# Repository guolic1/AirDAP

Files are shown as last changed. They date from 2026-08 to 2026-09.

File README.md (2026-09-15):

# AirDAP

基于 ESP32-S3 的无线调试器，支持 CMSIS-DAP 调试烧录和串口通信。
通过 USB 直连，或使用 Windows / Linux 主机服务将网络设备映射为 USB 调试器和串口。

支持蓝牙 / USB 配网、Wi-Fi 扫描、设备信息查看及 OTA 升级。

## 快速开始

从 [Releases](https://github.com/guolic1/AirDAP/releases/latest) 下载服务管理器和固件：

- **Windows**：双击服务管理器安装服务，可设置端口和开机自启。默认管理地址为 `http://airdap.localhost:8080`。
- **Linux**：按 [主机服务说明](host/README.md) 构建并安装 systemd 服务。
- **固件**：`app.bin` 用于 OTA；`full.bin` 用于首次烧录或恢复，写入地址为 `0x0`，会清除配网数据。

Windows 的 USB/IP 映射需安装 [usbip-win2 驱动和客户端](https://github.com/vadimgrn/usbip-win2/releases)。

## 项目目录

- [firmware/](firmware/README.md)：ESP-IDF 固件与构建说明。
- [host/](host/README.md)：Rust 主机服务、Web 管理页和服务安装工具。
- [circuit/](circuit/)：KiCad 原理图与 PCB。
- [docs/hardware-pinmap.md](docs/hardware-pinmap.md)：硬件引脚约定。

## 许可证

[MIT](LICENSE)。第三方依赖遵循各自的许可证。

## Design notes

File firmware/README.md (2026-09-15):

# 固件构建

目标芯片为 ESP32-S3，使用 ESP-IDF v6.1.0。准备 Git、Python 3.13+；Windows 还需安装 `uv`。首次配置需要联网，工具安装在 `firmware/.airdap-env/`。

## Windows（PowerShell）

从仓库根目录执行：

```powershell
cd firmware
uv run --locked python tools/setup.py
. .\get_env.ps1
idf.py build
```

## Linux（Bash）

从仓库根目录执行：

```bash
cd firmware
python3 tools/setup.py
. ./get_env.sh
idf.py build
```

`setup.py` 只需首次运行；以后在 `firmware/` 下激活环境，再执行 `idf.py build`。已有 ESP-IDF v6.1.0 时，可将其路径作为 `tools/setup.py` 的参数。

## 构建产物

- `build/airdap.bin`：APP 固件，用于 OTA。
- `build/bootloader/bootloader.bin`：bootloader。
- `build/partition_table/partition-table.bin`：分区表。
- `build/ota_data_initial.bin`：初始 OTA 数据。

需要包含上述四项的完整固件时，在已激活环境的 `firmware/` 目录执行：

```sh
idf.py merge-bin
```

生成 `build/merged-binary.bin`，完整烧录地址为 `0x0`。

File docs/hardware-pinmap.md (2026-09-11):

# AirDAP GPIO 分配表

| GPIO | 信号/功能 | 方向/模式 | 有效电平与说明 |
|---:|---|---|---|
| 0 | `BOOT_KEY` | 输入（固件内部上拉） | 低有效；R1 10 kΩ 外部上拉，SW1 按下接地；兼作 ROM 下载启动键 |
| 2 | `TARGET_VTREF_ADC` | ADC 输入 | U1 焊盘 6；R7/R8 100 kΩ 等值分压，`VADC = Vtarget / 2`；GPIO3 未连接 |
| 8 | `USB_VBUS_SENSE` | ADC/数字输入 | R18/R19 100 kΩ 等值分压，`VADC = VBUS / 2` |
| 9 | `V_SOURCE_STATUS` | 输入/开漏输出 | 连接 TPS2116 `ST` 和 TPS22919 `ON`；写 1 释放，写 0 禁止目标供电；禁止推挽输出高 |
| 10 | `LED_STATUS` | 输出 | 红色状态 LED，低亮、高灭 |
| 11 | `LED_NET` | 输出 | 绿色网络 LED，低亮、高灭 |
| 12 | `TARGET_SWCLK_TCK` | 输出 | SWD SWCLK / JTAG TCK；启动时保持低 |
| 13 | `TARGET_SWDIO_TMS` | 双向 | SWDIO / JTAG TMS；传输方向由 GPIO14 控制 |
| 14 | `SWDIO_DIR` | 输出 | 低：目标→ESP32；高：ESP32→目标；R17 100 kΩ 下拉 |
| 17 | `TARGET_TX_TDI` | 输出 | 目标 UART TX / JTAG TDI |
| 18 | `TARGET_RX_TDO` | 输入 | 目标 UART RX / JTAG TDO |
| 19 | `USB_D-` | USB 双向 | 原生 USB D-，经 R15 22 Ω 连接 USB-C |
| 20 | `USB_D+` | USB 双向 | 原生 USB D+，经 R16 22 Ω 连接 USB-C |
| 41 | `TARGET_nRST` | 输出 | GPIO 高时 Q1 导通并拉低目标 nRST；GPIO 低时释放复位 |

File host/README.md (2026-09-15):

# AirDAP 原生主机服务

Rust 实现的 Windows / Linux 服务。发布程序内嵌 Web 页面、BLE Security 2、USB 与网络协议；
运行时不需要 ESP-IDF 或额外的 OpenSSL DLL。
`host/` 统一存放服务、Web 资源和安装工具。

## 功能

| 功能 | 行为 |
| --- | --- |
| USB/IP | TCP 3260/3261 的 TLS-PSK DAP 与 UART 映射为 CMSIS-DAP 和 CDC COM/ttyACM |
| 自动恢复 | 保存桥接启用状态；进程重启恢复，挂载失败 1 秒后重试；断线不重放旧请求 |
| Web | 固定监听本机 `127.0.0.1`，同源校验和每次启动生成的 API token |
| 配网 | USB / 蓝牙选择、持续会话、设备扫描 Wi-Fi、SSID/RSSI/信道/加密/BSSID、选择热点连接 |
| 网络凭据 | 兼容原有 JSON；先私密保存再写设备，失败重试使用相同凭据，检查返回指纹 |
| 设备信息 | 网络 HELLO 查询版本/UUID/能力；物理 USB 固定诊断命令 |
| OTA | 上传检查版本/大小/SHA-256，确认后写非活动槽；网络重启后核对槽位、版本和启动确认 |
| 服务 | Windows SCM / Linux systemd，开机自启、异常退出重启，停止时等待当前设备操作完成 |

配网成功或失败后窗口都保持打开，直到“取消配网”。蓝牙每 25 秒续期，设备租期为 120 秒。
USB 配网仍遵循固件限制：需要独立 debug shell，SSID/密码仅支持可打印 ASCII。
USB OTA 可验证重新枚举和版本，但该 USB QUERY 没有网络 QUERY 的槽位确认字段。
BLE 使用固件既有的公开开发配网口令；本次迁移没有改变固件的安全边界。
没有新增网络 debug shell 端口。

## 构建与前台运行

在完整仓库的 `host/` 内使用 Rust 1.93 或更新版本，依赖由 `Cargo.lock` 锁定：

```sh
cargo build --release --locked
./target/release/airdap-service --data-dir ./local-data --http-port 8080 --usbip-port 3242
```

Windows 运行 `target\release\airdap-service.exe`，其余参数相同。
构建需要 C 编译工具、Perl 和 make（vendored OpenSSL/libusb）；Linux 还需系统的蓝牙服务 BlueZ。
Windows 可用 MSVC 构建环境，或在 Linux 中用 `x86_64-pc-windows-gnu` + MinGW 交叉编译：

```sh
rustup target add x86_64-pc-windows-gnu
CARGO_TARGET_X86_64_PC_WINDOWS_GNU_LINKER=x86_64-w64-mingw32-gcc \
  cargo build --release --locked --target x86_64-pc-windows-gnu
```

打开 <http://airdap.localhost:8080>。用 `--http-port 18080` 选择其他端口后，访问
`http://airdap.localhost:18080`。现代浏览器将 `.localhost` 解析到本机，无需修改 hosts 或公网 DNS；
服务仍只监听 `127.0.0.1`，原有 `127.0.0.1` / `localhost` 地址继续可用。
如果客户端不支持 `.localhost` 解析，可使用相同端口的 `127.0.0.1` 地址。
`--no-http` 关闭 Web；`--usbip-executable` 指定系统 USB/IP 客户端。
前台默认数据目录：Windows `%LOCALAPPDATA%\AirDAP\service`，Linux `$XDG_DATA_HOME/AirDAP/service`
或 `~/.local/share/AirDAP/service`。`service.log` 记录操作结果，轮转为 2 MiB × 3，不记录请求内容或凭据。
Linux 发布版使用构建机器的 glibc 基线，分发到较旧发行版时应在最旧目标环境重新构建。

## Windows 服务安装

推荐下载单文件 `AirDAP-Manager.exe`，双击并确认 Windows 管理员权限提示。
管理器内嵌本版本的 Rust 服务，使用 Windows 自带的 .NET Framework 图形界面，运行时不需要
PowerShell 脚本或单独解压服务程序。管理器仅在打开窗口时运行，关闭后不影响后台服务。

| 管理器操作 | 行为 |
| --- | --- |
| 安装服务 | 选择 Web / USB/IP 端口、是否开启 Web、是否开机自启；校验端口后安装并启动 |
| 更新服务 | 使用当前管理器内嵌的服务程序，保留原端口、自启设置、运行/停止状态和设备数据 |
| 应用设置 | 修改端口、Web 开关与开机自启；正在运行时停止并重新启动，失败时尝试恢复原设置 |
| 启动 / 停止 / 重启 | 操作 Windows SCM；停止等待当前设备任务结束，不强制终止 OTA |
| 卸载服务 | 注销服务并删除服务 EXE，保留配置、凭据、日志和不认识的文件 |
| 打开管理页面 | 打开已安装服务的 `http://airdap.localhost:所选端口` |

更新已运行的服务若启动失败，会尝试恢复旧程序并重新启动；恢复失败会显示错误并保留可用的诊断信息。
系统命令超时导致结果不确定时，保留程序/备份并要求检查状态，不报告成功或自动重复操作。
已停止的服务更新后仍保持停止，其新版本的启动情况需在点击“启动”后确认。
更新通过下载新版管理器并点击“更新服务”完成，当前不联网自动下载更新。
管理器是便携工具，不会将自身注册为后台进程或添加到“已安装的应用”；卸载通过管理器完成。

旧 `AirDAPNative` 服务可用“更新服务”迁移为 `AirDAP`。迁移保留原 `AirDAPNative` 程序/数据目录，
不复制或重新生成凭据；新安装使用 `AirDAP` 目录。同名的其他程序、自定义启动参数或同时存在两份
服务时会拒绝修改，须先核对旧安装。图形管理器与下述旧脚本不同，允许在卸载后复用权限正确的保留数据目录。

USB/IP 驱动不捆绑在管理器内；界面显示客户端/驱动检测结果，并提供官方签名驱动下载入口。
本次生成的管理器尚未进行代码签名。

命令行安装方式仍可使用：

先安装签名的 usbip-win2 导入驱动和客户端；usbipd-win 不能替代导入客户端。
停止占用相同端口的旧实例。在**管理员 PowerShell** 中执行：

```powershell
./install-windows.ps1 -Action install -Binary ./target/release/airdap-service.exe
./install-windows.ps1 -Action status
./install-windows.ps1 -Action stop
./install-windows.ps1 -Action start
./install-windows.ps1 -Action remove
```

交叉编译时将 `-Binary` 指向 `target/x86_64-pc-windows-gnu/release/airdap-service.exe`。
可设置 `-HttpPort`、`-UsbipPort` 和 `-NoHttp`。
例如安装到 Web 端口 18080：

```powershell
./install-windows.ps1 -Action install -Binary ./target/release/airdap-service.exe -HttpPort 18080
```

安装后访问 `http://airdap.localhost:18080`。端口范围为 1–65535，请选择未被占用且与 USB/IP 不同的端口。
服务名为 `AirDAP`，以 LocalSystem 运行，程序放入 `%ProgramFiles%\AirDAP`，
数据放入 `%ProgramData%\AirDAP`，ACL 仅授权 SYSTEM 与 Administrators。
命令行安装脚本拒绝覆盖已有服务、程序或数据目录；其 `remove` 只注销服务并保留程序及凭据。
Windows 服务账户下的蓝牙访问取决于适配器和权限，须在目标机器验证。

### 构建和验证 Windows 管理器

先构建 Windows 服务，再在 `host/` 中执行：

```powershell
.\manager\build.ps1 -ServiceBinary .\target\release\airdap-service.exe
```

默认输出到仓库 `build/releases/windows-x64/AirDAP-Manager.exe`。Windows x64 的 .NET Framework
`csc.exe` 直接编译，未添加 NuGet 或其他第三方生产依赖。

不修改系统的测试（参数保护、真实进程参数传递、内嵌程序、图形窗口和只读服务状态）：

```powershell
.\manager\build.ps1 -ServiceBinary .\target\release\airdap-service.exe -OutputDirectory ..\build\manager-check -Test
```

**仅在没有 AirDAP 服务及安装/数据目录的干净 Windows 测试环境中，以管理员权限执行：**

```powershell
..\build\manager-check\AirDAP-Manager.Tests.exe --system-test
```

该测试会实际安装和卸载服务，验证 Web 就绪、端口/自启修改、更新、旧名称迁移和数据保留，
并注入不能启动的测试程序验证更新/迁移回退。发现已有安装或数据会拒绝运行；失败时保留现场。
测试创建的服务不会配置设备或启用 USB 桥接。`*Tests.exe`、`AirDAP-Failure*.exe` 和预览图仅用于测试，
不得加入面向用户的发行包。

## Linux 服务安装

先安装发行版的 `usbip`、BlueZ，并确认内核支持 `vhci_hcd`。在本目录执行：

```sh
sudo sh install-linux.sh install ./target/release/airdap-service
sudo sh install-linux.sh status
sudo sh install-linux.sh stop
sudo sh install-linux.sh start
sudo sh install-linux.sh remove
```

安装时可依次指定 Web 和 USB/IP 端口，例如
`sudo sh install-linux.sh install ./airdap-service 18080 3242`，之后访问
`http://airdap.localhost:18080`。省略端口时仍使用 8080 / 3242。

注册 `airdap.service`，程序 `/opt/airdap/airdap-service`，数据 `/var/lib/airdap`。
使用 root 是为了访问 VHCI、USB 和系统蓝牙。systemd 限制系统文件写入；管理接口仅监听回环地址。
用 `systemctl edit airdap.service` 设置端口：先用空 `ExecStart=` 清除原值，再填写完整命令。
卸载保留数据和程序。更新现有安装时，先停止服务，再由管理员替换精确的可执行文件并启动。

## 旧版数据迁移

1. 停止旧桥接和服务，保留原数据目录作为备份。
2. 启动服务时直接使用原 `--data-dir`，或在两边均已停止时复制 `config.json` 与 `credentials/`。
   Linux 凭据文件必须为 0600、目录为 0700；Windows 服务数据须保留安装器设置的 ACL。
3. 使用原端口运行服务。已有 `bridge_enabled=true` 会恢复桥接；首次试运行可先改为 false。
4. 读取设备信息并核对后启用桥接。如需回退，使用旧版本发行包及备份配置。

同一数据目录不能同时运行多个服务实例，`service.lock` 进程锁用于阻止重复启动。
正式服务名统一为 `AirDAP` / `airdap.service`。安装器不会覆盖同名的其他程序或不认识的安装；
迁移前先停止并使用旧版工具注销旧服务，保留数据备份。
Linux 若存在 `airdap-native.service`，先停用旧单元并备份旧数据；新安装器会拒绝并存安装。
旧单元可留作备份文件（移出 `/etc/systemd/system/`），执行 `systemctl daemon-reload` 后安装新服务，
停止新服务再按上述权限约定将配置和凭据迁入 `/var/lib/airdap`，确认新服务正常后再清理旧程序。
Web 页面、JSON API 和凭据格式保持兼容。

## 验证

```sh
cargo fmt --check
cargo clippy --locked --all-targets -- -D warnings
cargo test --locked --all-targets
cargo build --locked --bins --examples
```

上述命令覆盖 Rust 单元和协议测试；管理器验证见上方 Windows 管理器章节。
当前不再提供独立的 HTTP、TLS-PSK/USB-IP 和 OTA 进程模拟测试脚本；
进程间交互和设备写入仍需结合实际服务与硬件验收，不能由这些单元测试代替。

2026-09-14 实机验证：Windows VHCI 成功枚举 CMSIS-DAP 与 COM，DAP_Info 读取通过，
COM 打开/关闭及 57600→115200 波特率配置通过；蓝牙与 USB 的配网握手、热点扫描、
凭据指纹确认和取消会话通过。蓝牙闲置 144 秒后仍可扫描和写入凭据，设备再次重启后的
首次连接也通过。Linux 原生服务通过真实 TLS-PSK 与设备通信，经 USB/IP 客户端读取 DAP_Info 成功。
网络 OTA 确认切换到原非活动槽且已确认启动；USB OTA 确认
断开、重新枚举和版本，随后用物理 USB 诊断核对镜像状态为 valid。使用同一份已验证固件测试，
没有改变固件版本。设备重启约 2.16 秒后旧 USB/IP 会话断开、约 2.37 秒开始重挂载，之后 DAP 可读；
这不是物理断电到 PnP 删除的精确时延测量。

实机发现并修复 Windows 驱动自动移除与显式卸载的竞态、USB OTA 重新枚举期间临时通信错误，
以及 Windows 蓝牙首次连接的 GATT 会话建立顺序。失败的卸载仅在确认本服务导出已消失后视为完成；
USB 枚举错误不视为断开证明，也不自动重放 OTA；Windows 使用显式 GATT 会话保持连接，取消时释放。

管理器已通过 Windows 编译、参数/归属校验、真实进程参数传递、内嵌服务和图形界面只读验证。
当前会话没有管理员权限，尚未执行管理器 `--system-test`；真实 SCM 安装、更新回退、名称迁移和卸载
仍需管理员环境验收。尚未执行 Linux systemd 实际安装、Linux VHCI 导入、实物 Wi-Fi 密码写入、
目标芯片烧录或 UART 线缆回环；也未做破坏性回滚故障注入。
这些场景不能由成功构建、模拟测试、DAP 信息读取或 COM 打开代替证明。

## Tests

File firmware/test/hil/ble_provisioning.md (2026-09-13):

# BLE Security 2 provisioning hardware-in-the-loop acceptance

Run this checklist only on an explicitly selected, recoverable development
AirDAP and a dedicated test access point. Record the board revision, module
ordering code, ESP-IDF version, firmware revision, AirDAP device ID, test AP,
client OS/Bluetooth adapter, and the Security 2 credential fingerprint. Never
record the Wi-Fi password. The Security 2 username and PoP are intentionally
public.

This procedure writes flash and changes Wi-Fi configuration. Obtain approval
for the selected board before running it. Host tests and a successful ESP-IDF
build do not replace the RF, persistence, GPIO0, and restart observations.

## 1. Build the public Security 2 credential

Activate ESP-IDF and build the standard firmware. The public username
`wifiprov`, PoP `abcd1234`, salt, and verifier are already compiled into the
application; no credential image or injection step is required:

```sh
cd firmware
idf.py build
idf.py -p <airdap-programming-port> flash
```

Restart and monitor AirDAP. Record `button bindings`, then use `button defaults`.
The following steps assume the default mappings; restore custom bindings after
acceptance. Confirm BLE is not advertising before a button
press. Hold `BOOT_KEY` until the red STATUS LED starts its 500 ms on/off
slow flash at two seconds. With USB priority, NET must remain off until the
provisioning window opens; during active provisioning it flashes 100 ms on/off.
Before releasing it, confirm BLE has not initialized or started advertising
and an attached debug-shell session remains connected. Release the button and
confirm:

- the `ADP-...` BLE service appears;
- its name matches the USB/device identity;
- the logged credential fingerprint is
  `C5D2AA01B4DDA9A67CBE111D61B9F0CBBD3A9F7A7935E85E570A881C7EE03080`;
- no SSID or Wi-Fi password appears in logs.

Use the AirDAP provisioning tool. It discovers active AirDAP advertisements and
supplies the public Security 2 credential automatically; the Wi-Fi passphrase
is still prompted privately:

```sh
python tools/airdap-provision.py
```

After the client connects, confirm the device reports a negotiated ATT MTU of
at least 409 bytes, so the 406-byte Security 2 session request fits in one
characteristic write, and the request is not rejected with `Invalid PDU`.

On Windows, also verify with a device that is not paired in OS settings:
connection must proceed without a system pairing request or the approximately
60-second device-association wait. Confirm Security 2 establishes a session and
the Wi-Fi selection prompt appears. For this connection-only regression check,
cancel at that prompt without submitting credentials, then close the BLE
window and verify the previous Wi-Fi connection resumes. Repeat on Linux when
a Linux Bluetooth host is available; host unit tests do not establish RF timing.

## 2. Authentication failure and cancellation

Open a new window and use the AirDAP launcher for this negative-only test,
substituting the observed device ID and a deliberately incorrect PoP:

```sh
python tools/airdap_esp_prov.py \
    managed_components/espressif__network_provisioning/tool/esp_prov/esp_prov.py \
    --transport ble \
    --service_name <ADP-device-id> \
    --sec_ver 2 \
    --sec2_username wifiprov \
    --sec2_pwd intentionally-wrong-pop
```

Confirm the secure session is rejected, the stored Wi-Fi configuration is
unchanged, and the BLE window remains available. Hold `BOOT_KEY` until the
red STATUS LED starts flashing slowly again, then release it. Confirm BLE advertising and
the provisioning service stop, the mode no longer reports an active
provisioning attempt, and the prior Wi-Fi configuration remains in effect.

## 3. Timeout cleanup

Open another window and do not connect a client. Confirm the service disappears
after 120 seconds and does not return without a new two-second
hold-and-release. Confirm the previously committed Wi-Fi configuration and
normal USB interfaces remain usable. This is the resource-lifecycle acceptance
check; a client disconnect alone is not evidence that the firmware stopped the
BLE service.

## 4. First provisioning and reboot recovery

If necessary, perform the ten-second reset from section 5 first. Open a window,
run the AirDAP provisioning tool, select the dedicated test AP, and enter its
password interactively. Required observations:

- the Security 2 session succeeds and Wi-Fi association reaches DHCP;
- the device becomes provisioned and online;
- the client reports provisioning success before the service disappears;
- BLE stops and releases its resources within 30 seconds after success;
- a power cycle reconnects to the same AP without opening BLE;
- a fresh two-second hold-and-release can open a new window using the same public
  Security 2 credential fingerprint.

Repeat with an incorrect AP password before the successful attempt. Confirm the
failed candidate is not published. For the reset-specific check, reconnect the
raw Espressif client command from section 2 with the correct public PoP and
`--reset`, then rerun `python tools/airdap-provision.py` and enter the correct AP
credentials. Confirm the prior committed Wi-Fi configuration is restored on
cancel/timeout and no credential value appears in logs except the documented
public fingerprint.

## 5. Ten-second network reset and GPIO0 release guard

With the device provisioned, hold `BOOT_KEY` continuously. Confirm STATUS stays
off before two seconds, then flashes with 500 ms on/off without initializing
BLE or disconnecting the debug shell. Continue holding until STATUS changes to
200 ms on/off at six seconds, then 60 ms on/off at ten seconds. NET must keep
its current network indication throughout the hold. Keep it pressed briefly and confirm AirDAP
has not cleared configuration or restarted while GPIO0 remains low. Release the
button and confirm STATUS turns off before AirDAP clears configuration and
restarts normally rather than entering the ROM download mode. The debug shell
disconnect caused by that restart is expected. After restart:

- provisioning state is `unprovisioned` and Wi-Fi does not reconnect;
- the reserved pairing and network-authentication slots are absent;
- BLE remains off until another two-second hold-and-release;
- the new window reports the same Security 2 credential fingerprint and
  accepts the public PoP.

Finish by clearing the test Wi-Fi configuration. Record that anyone within BLE
range who knows the public credential can provision during a physically opened
window; this test does not establish per-device owner authentication.

## 6. Click feedback

With no provisioning window open, press and release BOOT_KEY briefly. STATUS
must stay off while pressed and while waiting for a second press; 300 ms after
release begins, confirm one 100 ms flash and one single-click log. Repeat with
two short presses separated by less than 300 ms: confirm two 100 ms flashes
separated by 100 ms off, one double-click log, and no single-click log. Neither
gesture should start BLE, reset either MCU, or change target power. NET follows
the selected route (the default double click toggles NETWORK/AUTO).
Start another ordinary press during a completion flash and confirm its
40 ms press confirmation cancels the remaining flash sequence.

Observe long-hold release bounce if suitable test equipment is available: a
release shorter than 200 ms must retain the current flash phase and not execute
the action or repeat threshold events. Releasing between 6 and 10 seconds with
default bindings must log `hold6 command=none` and never open BLE or clear data.
Record measured timing separately from
host-test results; polling and task scheduling can affect real flash durations.

## 7. Persistent bindings and DAP selection

Record `button commands` (thirteen entries) and `button bindings` (five gestures).
Set `button bind hold6 dap-auto`, restart and confirm the binding and previously
selected route both survive. Restore the defaults and confirm that this change
survives a second restart. Invalid gestures/commands or trailing tokens must fail without
changing the stored bindings. Save and restore any pre-test custom mappings.

Select AUTO first. With USB data attached, Wi-Fi online, and DAP disconnected, double-click and
confirm `dap-route=network`. Verify authenticated pyOCD DAP access over TCP and
verify that wired DAP and target CDC disappear. Only the independent debug
shell should remain enumerated. Unauthenticated network access must remain rejected.
Disconnect DAP and double-click again; confirm `dap-route=auto`, wired DAP works,
and network DAP is rejected. With a DAP owner or OTA active, verify the selection
command reports busy and preserves the current route and transfer. Restart and
confirm the last selected mode is restored. Explicit NETWORK selection must
survive USB detach/reattach and reboot until another route command changes it.
Test both NETWORK and AUTO after a complete power cycle; confirm NETWORK never
briefly enumerates wired DAP/CDC at startup and AUTO follows physical USB presence.
Check version 1 migration with the old default double binding and another custom
binding; only the double binding should change. Then explicitly bind double to
`dap-toggle`, restart, and verify that this legacy choice is retained. Restore
the user's original bindings and mode after testing.

On a recoverable board only, map double-click to `clear-network-restart` and
observe that restart cannot occur before 200 ms of stable release. A new press
during that guard must cancel the pending clear. Restore defaults afterward.

## 8. Optional device command bindings

Obtain exclusive access to the identified AirDAP and target before these checks.
Record the current bindings and test each new command by binding it to `hold6`.
Restore the bindings after acceptance. Do not infer these results from host tests.

- `restart`: confirm a normal AirDAP reboot with network and button configuration
  intact. Also map to double-click and check the 200 ms release guard; pressing
  again during the guard must cancel restart.
- `target-reset`: scope target nRESET for a 100 ms low pulse and release. Confirm
  AirDAP remains running and SWD is not acquired. Measure scheduling tolerance.
- `wifi-toggle`: disable the radio, confirm no reconnect, and retain USB shell.
  Enable it and confirm reconnection with the saved credentials. Repeat with no
  saved SSID and after editing credentials while off. Reboot restores enabled.
- `target-power-toggle`: scope GPIO9 and target voltage while toggling permission.
  Confirm only open-drain pull-low/release behavior, with no push-pull high.
  External ST low must not change which permission the next press selects.
- `target-power-cycle`: scope the 500 ms disable interval followed by release.
  Verify the actual target reset/power behavior for its load and power source;
  an independently powered target may remain on.

With DAP connected, OTA active, or provisioning active, verify each new command
is rejected without changing the target, radio or AirDAP state. During a reset
or power-cycle pulse, DAP acquisition and OTA writes must remain blocked. Repeat
with USB debug shell disabled to confirm physical button operation is independent.

## 9. Complete simulated gestures over USB

Record bindings and use `none` for destructive actions during indicator-only
checks. Run `button simulate single`, `double`, `hold2`, `hold6`, and `hold10`
(with the full `button simulate` prefix each time). Confirm the matching STATUS
patterns and exactly one terminal gesture, using the same configured command
path as the physical button. Holds take real time and automatically release.
`button status` reports the queued/running gesture, then `idle`; a second
simulation during the first must fail. Legacy `button press`/`release` must fail.

Close USB shell after submitting `button simulate hold6` and verify the gesture
finishes normally. Reconnect and confirm `button status` is idle. Interrupt an
unfinished simulated hold with a physical press; confirm the simulated hold
action does not execute and the physical press begins a fresh gesture. A
simulation requested during a physical gesture must not alter that gesture.
Restore the saved bindings after the test. Obtain separate authorization for
commands that reboot, clear configuration, reset the target, or change power.

## 10. NET route and connection indication

On the selected board, record bindings, route, and Wi-Fi configuration before
testing. Use the dedicated test AP for disconnect/reconnect checks.

1. With Wi-Fi online, select `USB`: NET is off while network management remains
   available. Select `NETWORK` with USB still attached: NET stays on, the wired
   DAP/CDC disappear, and the independent debug shell can reconnect.
2. Select `AUTO`. Keep independent board power and unplug only the USB data
   cable: NET comes on while Wi-Fi remains online. Reconnect USB: NET turns
   off. Compare `system-info` uptime before/after to exclude a reboot.
3. In `NETWORK`, interrupt the test AP. Confirm 500 ms on/off continues across
   reconnect attempts and retry backoff, then becomes steady on only after
   an IP address is acquired. With Wi-Fi disabled or unconfigured, NET is off.
4. Open provisioning with USB priority active. NET flashes 100 ms on/off even
   with USB attached. Check success, cancellation, and timeout separately:
   the subsequent indication must reflect the current route and Wi-Fi state.
5. With NET steady on, use a harmless single-click binding and verify STATUS
   completion flashes do not turn NET off. Observe both LEDs during hold
   thresholds without binding those gestures to destructive commands.

Restore bindings, route, AP availability, and Wi-Fi settings. Record visual
observations and measured timings separately from host-test results; this
procedure does not establish target UART loopback or DAP electrical timing.

## 11. Host service provisioning sessions

Obtain authorization for the exact physical device, test AP and network-key
replacement before these checks. Stop the USB/IP bridge and target tools.

For both BLE and USB, select the transport in the host page and start
provisioning. Confirm the session stays open after generating a local credential,
after scanning APs, after a wrong Wi-Fi password, and after a successful DHCP
connection. Check RSSI, channel, BSSID and authentication against the test AP.
Select another SSID and connect again without leaving the window. Refresh the
page and confirm the same session is restored; Escape must not close it.
Cancel explicitly, then verify that Wi-Fi and the saved network credential still
work. USB requires the new `wifi capabilities`, `scan`, `ap` and hidden `pair`
interfaces. Inspect command history and logs for absence of passwords and PSKs.

For BLE, keep the page open beyond two minutes and repeat an operation. Stop the
host process or remove the BLE connection and confirm the device closes the
window within the 120-second lease. Confirm a legacy client still receives its
successful Wi-Fi status before the 30-second compatibility cleanup. Repeat with
a failed connection to verify cancel restores the last committed configuration.

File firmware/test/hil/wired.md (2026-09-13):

# Wired firmware hardware-in-the-loop acceptance

Run this checklist on the exact populated AirDAP PCB and record the board
revision, ESP32-S3 module ordering code, target MCU, host OS, tool versions,
and measurements. Passing the firmware build or host unit tests is not a
substitute for this checklist.

## Automated evidence helper

Install current pyOCD, PyUSB, and pyserial releases in an isolated Python
environment. On Windows, PyUSB also needs a libusb backend capable of opening
the WinUSB-bound Vendor interfaces. On Linux, grant the user access to the
device with an appropriate udev rule.

With target UART TX/RX connected as a loopback and a known binary reference
image selected for the target, run:

```sh
python test/hil/wired_smoke.py \
    --serial ADP-001122334455 \
    --board-revision <pcb-revision> \
    --module-ordering-code <esp32-s3-module-ordering-code> \
    --reference-target <target-board-and-mcu> \
    --exercise-reset \
    --cdc-port <target-uart-com-port> \
    --program-image <reference-image.bin> \
    --target <pyocd-target-type> \
    --base-address <target-flash-address> \
    --reliability-cycles 100 \
    --output <evidence.json>
```

This command performs destructive sector erase/program operations on the
reference target. It validates the USB interface and endpoint layout, USB and
DAP serial agreement, DAP capabilities, the 508-byte response boundary,
stable DP IDCODE, reset command, CDC loopback line codings, a 500 kHz/1 MHz/
5 MHz program/readback sweep, and the requested reconnect/program/readback
cycles. The JSON records whether the optional Vendor Bulk debug interface is
present. The JSON also includes tool versions, image hash, timings, and
hardware identifiers. Run the command again with the recorded `--serial` after
an unplug/replug to prove serial stability.

The helper cannot observe analog or electrical behavior. Oscilloscope traces,
ADC comparison, contention checks, GPIO9 open-drain behavior, reverse-current
tests, and Windows driver binding still require the manual steps below.

## 1. Boot safety

Follow `bootloader.md`. Capture SWCLK, SWDIO, SWDIO_DIR, target nRESET control,
GPIO9, and target UART TX from reset assertion until the application starts.
Confirm that no unsafe pulse occurs before `bootloader_before_init()`.

## 2. Flash and startup

```sh
idf.py -p <airdap-programming-port> flash monitor
```

Confirm that the log reports target VTref and USB VBUS without an ADC or GPIO
initialization error. Record the measured voltages at the ADC pins and compare
them with the logged values, including divider ratios and tolerances.

## 3. USB descriptors and Windows binding

Confirm one composite device with VID `303A`, PID `4021`, and a stable serial
`ADP-<12 hex digits>` appears. Verify:

- interface 0 is class `FF`, subclass `00`, protocol `00`;
- its interface string contains `CMSIS-DAP`;
- Bulk OUT `0x01` precedes Bulk IN `0x81`, both with 64-byte max packets;
- interface 0 binds WinUSB through the Microsoft OS 2.0 descriptor;
- interfaces 1/2 enumerate as CDC ACM with endpoints `0x82`, `0x03`, `0x83`;
- when the debug-shell build is selected, interface 3 enumerates as class
  `FF/00/00`, is named `AirDAP Debug Shell`, and has Bulk OUT `0x04` followed
  by Bulk IN `0x84`;
- interfaces 0 and 3 bind WinUSB through the Microsoft OS 2.0 descriptor;
- unplug/replug preserves both the USB serial and driver bindings.

Repeat descriptor inspection on Linux with `lsusb -v` when available.

## 4. CMSIS-DAP and SWD

With a known-good Cortex-M reference target and a current limiting supply:

1. Run `pyocd list` and confirm the AirDAP CMSIS-DAP v2 interface is selected.
2. Connect at 500 kHz, read DP IDCODE repeatedly, and record the value.
3. Exercise DP and AP reads/writes, including a deliberately disconnected
   target to observe WAIT/FAULT/error handling.
4. Erase, program, and verify a known reference image.
5. Repeat connect/program/verify at 1 MHz and 5 MHz. Treat 10 MHz as an
   optimization result, not a Stage 1 requirement.
6. Perform at least 100 reconnect/program/verify cycles and record failures.

Probe SWCLK, SWDIO, and GPIO14 during read and write transfers. Confirm the
external direction signal changes only across the configured turnaround and
that SWDIO contention is absent.

## 5. CDC target UART

Connect GPIO17/GPIO18 to a reference UART or loopback fixture. Verify both
directions at 9,600, 115,200, and 1,000,000 baud. Change baud, data bits,
parity, and stop bits from the host and confirm supported CDC line coding is
applied. Confirm unsupported mark/space parity is rejected without crashing or
changing the last valid configuration.

## 6. Optional Vendor Bulk debug shell

For a build made with `sdkconfig.debug-shell.defaults`, run:

```sh
python tools/airdap-shell.py --serial <ADP-serial>
```

Confirm this does not open or change `AirDAP Target UART`. Run `help` and verify
that `help`, `identity`, `config-status`, `status`, `swd-idcode`, and `restart`
are listed in cyan and the descriptions remain in the terminal's default
color. Confirm `version` is not listed and reports a red unrecognized-command
error when entered. Verify the prompt is cyan, successful `config-status` and
`status` results are green, and `config-status extra` and `status extra` usage
guidance is yellow. Type `con`, press Tab, and verify it completes to
`config-status `. Type `sta`, press Tab, and verify it completes to `status `.
On an empty line, press Tab and verify all six commands are listed.
Type `s`, press Tab, and verify `status` and `swd-idcode` are listed in cyan on
separate lines before the prompt restores `s`. Use Left/Right, Home/End,
Backspace, and Delete to edit text at the beginning, middle, and end of a command
without prompt-width or cursor drift. Submit multiple commands, type a prefix,
and verify Up/Down only visits matching history; verify moving down past the
newest match restores the unsubmitted draft and cursor. Reconnect with
`--color never` and verify the same interaction is plain text, then return to the
default color mode. Reconnect the shell and verify the previous session's
history is unavailable. While application logs are arriving, pause with the
cursor in the middle of an unfinished command and verify each log retains its
original formatting and is followed by the intact colored prompt, input, and
cursor position. Run `identity` and confirm its USB serial matches the composite
device and CMSIS-DAP `DAP_Info` serial, its device ID uses the same stable
source, its UUID has 32 hexadecimal digits, and its `firmware_version` value
matches both the exact Git tag on the built commit or, when untagged, its
seven-character Git hash and the version reported by the USB OTA query. Run
`config-status` and verify it reports the current decimal schema version and
either `provisioned` or `unprovisioned`, without a password, PoP, PSK, private
key, Wi-Fi credential, pairing record, or authentication-material value. Run
`status` and verify decimal target voltage, USB VBUS voltage, uptime, and free
heap fields. With OpenOCD and other CMSIS-DAP clients closed, run `swd-idcode
100` against the known-good reference target. Confirm it reports the same
nonzero DP IDCODE
recorded in section 4, then repeat once with the target disconnected and confirm
the command reports a red error and the target-side SWDIO line is released.
Confirm normal ESP application logs still appear on the primary console.
Finally, run `restart`, verify the yellow acknowledgement is received in full
before disconnect, and confirm the composite device re-enumerates with the same
serial number. Repeat with Bulk IN deliberately left unread past the firmware's
bounded timeout and confirm AirDAP does not restart.

## 7. Config-store hard-power-cycle fixture

Use a dedicated development board because this fixture replaces the normal
application and erases its flash. It writes only fixed, non-secret marker bytes;
never substitute production credentials. From `firmware/`, activate ESP-IDF,
then build and flash the standalone fixture into an ignored build directory:

```sh
airdap_firmware_dir=$(pwd)
idf.py -C test/hil/config_store \
  -B "$airdap_firmware_dir/build/config-store-hil" \
  -D IDF_TARGET=esp32s3 \
  -D SDKCONFIG="$airdap_firmware_dir/build/config-store-hil/sdkconfig" \
  -D DEPENDENCIES_LOCK="$airdap_firmware_dir/build/config-store-hil/dependencies.lock" \
  erase-flash flash monitor
```

Wait for `STAGE_WRITE_OK`, disconnect all board power without issuing a software
restart, wait five seconds, reconnect power, and resume the serial monitor. The
fixture must print `STAGE_RESTORE_OK`, proving that the friendly name,
provisioning state, and all three public blob slots were recovered through
`airdap_config_store_init()` and public getters. At `STAGE_CLEAR_OK`, repeat the
same hard power removal. The third boot must print `PASS`: the Wi-Fi and pairing
slots remain absent, provisioning is reset, and the unselected friendly name
and authentication marker remain present. Any `FAIL` or panic fails P1-T2.

Erase the fixture before returning the board to normal firmware. Host fake-NVS
tests do not replace this procedure, and this procedure validates logical
retention/clear behavior rather than laboratory recovery of obsolete flash
pages.

## 8. Reset and target power

- Issue `DAP_ResetTarget` and verify a 1 ms asserted reset pulse at the target.
- Exercise `DAP_SWJ_Pins` with nRESET selected and verify asserted/released
  polarity at both GPIO41 and the target connector.
- With USB input present and absent, exercise GPIO9 only as open drain. Confirm
  that firmware never drives it push-pull high.
- Test target self-power and AirDAP-provided power separately. Confirm no
  reverse current path and verify the TPS2116 status readback interpretation.
- On shutdown, confirm SWCLK is low, SWDIO is high impedance, reset is released,
  and GPIO9 can actively disable AirDAP-provided target power.

## Exit evidence

Store USB descriptor captures, oscilloscope traces, voltage measurements,
pyOCD logs, programmed image hash, UART results, and the 100-cycle result with
the tested board revision. Only then may roadmap Stage 1 be marked complete.

## DAP/UART transport selection

After an authorized firmware update on the identified board, verify with a paired
Wi-Fi client and a USB host. Stop active DAP operations before selecting a route.
The default BOOT_KEY double click toggles NETWORK/AUTO; other route commands can
be assigned to a gesture using `button bind` (record and restore its old binding).

1. In `USB`, verify CMSIS-DAP and target CDC enumerate, TCP 3261 rejects new
   connections, and authenticated DAP requests on 3260 return `busy`. Verify
   authenticated management/OTA query still works on 3260.
2. Select `NETWORK`. Verify the active CMSIS-DAP and target COM device disappear
   from the host, and an open CDC handle no longer forwards target data. Windows
   may retain hidden historical devices; check currently present devices.
   Confirm only `303A:4022` debug shell remains and reconnect `airdap-shell.py`.
   Verify authenticated network DAP and UART work.
3. Select `USB` again with a network UART connection open. Verify that connection
   closes and releases TX ownership, 3261 stops listening, and `303A:4021` DAP/CDC
   return. Verify shell reconnects on its original interface and target CDC works.
4. Select `AUTO`: unplug the USB data cable while keeping independent board power
   and verify network data becomes usable. Reconnect USB and verify network DAP
   is rejected and network UART closes. A power-only cable must not select USB.
5. Repeat both directions, including removal during re-enumeration. Verify no
   shell bytes reach DAP endpoints, no stale UART data/ownership survives, and
   reboot restores the last saved mode (test both `NETWORK` and `AUTO`). Repeat with debug shell disabled if that build is used.

Host tests and builds do not establish these enumeration, electrical, cable,
operating-system driver, and live TLS outcomes.

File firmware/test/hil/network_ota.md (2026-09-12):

# Authenticated network OTA acceptance

Reserve one identified, recoverable 8 MiB AirDAP for the entire run. Wait for
all other HIL agents to finish and acknowledge release before opening USB,
BLE, CDC or network clients. Keep sole ownership through rollback/recovery;
close all handles and explicitly release the device afterward. Run hardware
tests serially. Retain a valid baseline image and a recovery path. Record
device ID, IP, port, credential path (never contents), commits, image hashes,
before/after QUERY, logs and each assertion.

## Baseline

Run host tests and ESP-IDF build gates first. Verify the merged TCP 3260
control and TCP 3261 UART baseline, including shared token and disconnect
revocation. If the running firmware lacks network OTA, install the new image
with the existing USB OTA tool. Confirm the same identity and VALID image,
then close the shell and query through `airdap-network-update.py --query`.

An existing baseline can report UART TX busy after re-enumeration because
host line-coding activity acquired USB TX. Record this separately; opening
and normally closing the selected CDC port releases that session. This
workaround is not evidence that OTA permanently owns UART.

## Rejections and cleanup

Use the Python Client in `firmware/tools/airdap-network-update.py` for bounded
fault injection. Use the next frame sequence except in deliberate replay tests.

1. Wrong PSK must fail TLS. HELLO without AUTH must reject every OTA opcode.
   TCP 3261 must reject OTA opcodes even after authentication.
2. Save QUERY's addresses/version. BEGIN zero or beyond capacity must fail.
3. Acquire USB DAP (or NETWORK DAP with USB absent) and network UART TX. Join
   the owner's token for control as needed. BEGIN must release both owners;
   DAP operations and both UART TX acquisitions must remain blocked while
   receiving/committed. Closing a bound sibling intentionally revokes all
   owner connections, so keep them open until testing that failure path.
4. Reject wrong offset, overrun and incomplete COMMIT. ABORT restores admission
   without selecting the incomplete slot. A duplicate COMMIT is invalid state.
5. Close TLS mid-upload and mid-frame; also test owner idle expiry and a bound
   sibling disconnect. After teardown, a new owner can BEGIN at offset zero.
   Query retains the original running version/address. Complete a later update
   to prove recovery rather than relying solely on the status response.
6. Upload a corrupted image. COMMIT must fail validation and leave the valid
   image bootable. Do not corrupt boot metadata.

## Successful updates

Build known-good revisions A and B with distinct Git-derived versions. Run
`airdap-network-update.py <ip> <B.bin> --credential <path>` from A. Require
identity match, running address equal to A's inactive address, version B and
confirmed=true. Repeat B to A. Also close the connection after COMMIT, reconnect
and REBOOT; boot selection must survive disconnect, and the ACK must precede
restart. Recheck USB DAP, UART and authenticated control afterward.

## Unconfirmed rollback

Use a disposable untracked copy of B that calls `esp_restart()` after USB
initialization but before `airdap_ota_confirm_running_image()`. Build with the
normal rollback/artifact gates. Never disable gates or burn eFuses. Upload
through authenticated network OTA from valid A. Expect the normal updater to
fail its final verification because B is not the final running image. Retain
serial logs proving B starts PENDING_VERIFY, restarts unconfirmed, and the
bootloader returns to valid A. Confirm identity, original address/version and
confirmed=true, then complete another normal update.

If serial capture or recovery conditions are unavailable, record rollback as
unverified. Unit tests do not prove physical boot selection or persistence.

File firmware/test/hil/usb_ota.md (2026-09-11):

# USB OTA hardware-in-the-loop acceptance

Run this checklist on a recoverable AirDAP with the confirmed 8 MiB flash.
Record the board revision, module ordering code, host OS, ESP-IDF version, USB
serial, build revisions, command output, and observed running versions. Keep a
serial programmer available: the first layout migration and recovery from a
deliberately broken test image require it.

## 1. Install the A/B baseline

Build a known-good revision A and retain its three binaries. Verify that the
decoded partition table contains `otadata`, two 4032 KiB (`0x3F0000`) slots at
`0x20000` and `0x410000`, and no `factory` partition. Then perform the one-time full flash:

```sh
cd firmware
idf.py build
idf.py -p <airdap-programming-port> flash
python tools/airdap-update.py --help
```

After USB enumeration, record the `ADP-...` serial. Confirm normal CMSIS-DAP
and target-UART behavior before continuing.

## 2. Successful A to B update

Build a distinct known-good revision B, close every debugger using AirDAP, and
run:

```sh
python tools/airdap-update.py \
    --serial ADP-001122334455 \
    build/airdap.bin
```

Required observations:

- no reset or GPIO0 press is needed;
- upload reaches 100%, commit succeeds, and USB disconnects;
- the same USB serial reconnects within the configured timeout;
- the script reports revision B's running version;
- CMSIS-DAP and target UART still work after restart.

Power-cycle AirDAP, then install the same known-good B image once more. Record
that the updater reports B as both the previous and post-reconnect running
version; this also exercises the opposite OTA slot.

## 3. Interrupted upload retains the running slot

Start an update from B to another valid image and disconnect USB or press
Ctrl-C after progress begins but before commit. Reconnect power if necessary,
then verify that B still starts and that its CMSIS-DAP and target-UART functions
remain usable. Run the same update again from offset zero; resume from a prior
offset is intentionally unsupported.

## 4. Unconfirmed image rolls back

Create a disposable HIL-only revision C that deterministically calls
`esp_restart()` after USB initialization but before
`airdap_ota_confirm_running_image()`. Do not commit or distribute this fault
injection. Build C, install it through `airdap-update.py`, and retain the full
serial boot log.

Required observations:

- C is selected and starts once;
- C restarts before confirming `PENDING_VERIFY`;
- the ESP-IDF bootloader excludes C and boots the prior valid B slot;
- the same USB serial reconnects and B's running version is reported;
- another normal B-to-D update succeeds afterward.

If any step fails, recover with the serial programmer and the retained
baseline binaries. Host unit tests and a successful build do not replace these
power-loss and boot-selection observations.

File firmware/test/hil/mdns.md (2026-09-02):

# mDNS discovery HIL

This procedure proves the RF and LAN boundary that host unit tests cannot:
AirDAP must publish its current station address as `_airdap._tcp.local` after
DHCP succeeds, replace the record after an address change, and stop publishing
when the station loses its IP. It also compares the TXT firmware value with the
same `device_identity` value exposed over USB.

Flashing, updating, restarting, or changing Wi-Fi credentials requires explicit
authorization for the selected development board. Use a dedicated test AP and
non-production credentials. Do not place credentials in command arguments,
logs, captures, or this repository.

## Preconditions

1. Build and install the Debug Shell profile described in
   [`../../README.md`](../../README.md), preserving the standard AirDAP
   partition table. Record the device USB serial and built commit.
2. From Windows, run `uv run python firmware/tools/airdap-shell.py`, then use
   interactive `wifi set`. Wait until `wifi status` reports `wifi=online`.
3. Keep the shell open so `mDNS service published` and `mDNS service withdrawn`
   lifecycle logs can be correlated with host observations. Do not treat logs
   alone as proof of a LAN announcement.
4. Put one Linux host and one Windows host on the same broadcast domain as the
   test AP. Linux needs Avahi client tools. Windows needs a DNS-SD browser such
   as Apple's `dns-sd.exe`.

## Initial announcement and identity

On Linux:

```sh
avahi-browse --resolve --terminate _airdap._tcp
```

On Windows, first browse for the instance and then resolve the exact instance
name returned by the browse:

```powershell
dns-sd.exe -B _airdap._tcp local
dns-sd.exe -L ADP-001122334455 _airdap._tcp local
```

For both hosts, record and check:

- one instance named exactly like the USB `device_id`;
- hostname `airdap-<12 lowercase MAC digits>.local`;
- the current DHCP address and SRV port 3260;
- exactly the seven TXT keys `id`, `proto`, `fw`, `cap`, `state`, `dap_port`,
  and `uart_port`;
- `id` equals the USB device ID, `fw` equals the Debug Shell `identity`
  firmware version, `proto=1`, `state=idle`, `dap_port=3260`, and
  `uart_port=3261`;
- no SSID, password, PoP, PSK, token, or other credential appears.

## Address replacement and offline withdrawal

1. Use the test AP's DHCP controls to give the board a different address, then
   reconnect it without rebuilding the firmware.
2. Wait for `wifi=online` and a new `mDNS service published` log. Repeat the
   Linux and Windows resolve commands and confirm that only the new address is
   returned by a fresh query.
3. Disconnect or power down the test AP. Confirm `wifi status` no longer reports
   online and observe `mDNS service withdrawn` after the station loses its IP.
4. A host cache may retain the old record until its TTL expires. Do not count a
   cached entry as a live advertisement; use a fresh browse after cache expiry
   or capture new multicast responses and confirm the offline device sends
   none.
5. Restore the AP. Confirm automatic Wi-Fi recovery and resolve the service
   again from both hosts. The record must contain the current address and the
   same device ID and firmware version, with no stale duplicate instance.

Record the board serial, firmware version, AP/test-host OS versions, old and new
addresses, command outputs, and relevant timestamps outside Git. This procedure
does not authenticate the discovered device or prove that the future TCP
services are listening.

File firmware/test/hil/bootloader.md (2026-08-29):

# Bootloader board-level verification

The host unit test proves the GPIO programming contract, but it cannot prove
physical levels between reset release and application startup. Run this check
on the AirDAP PCB before considering the bootloader hardware-safe.

## Equipment and setup

- AirDAP PCB with the exact ESP32-S3-MINI-1U ordering code recorded;
- oscilloscope or logic analyzer referenced to AirDAP ground;
- target disconnected for the first run;
- probes on ESP32 EN, GPIO9, GPIO12, GPIO13, GPIO14, GPIO17, GPIO18, and GPIO41.

Flash `bootloader.bin`, `partition-table.bin`, and `airdap.bin` from one clean
build. Before flashing, run `python tools/verify_bootloader.py --build-dir
build` in the activated ESP-IDF environment and retain its passing output with
the build artifacts. Trigger the capture on the rising edge of EN and retain
the interval from reset release through the `AirDAP firmware started` log
message.

## Required observations

| Signal | Required result after the AirDAP hook runs |
|---|---|
| GPIO12 / SWCLK | Low, without a positive pulse |
| GPIO13 / SWDIO | High impedance |
| GPIO14 / SWDIO DIR | Low, target-to-AirDAP |
| GPIO41 / target reset control | Low; target nRESET remains released |
| GPIO9 / power status-control | Open-drain released; it must not source the shared net |
| GPIO17 / target UART TX | High, without a negative pulse |
| GPIO18 / target UART RX | High impedance |

Repeat the capture for power-on reset, EN reset, and software reset. Then test
with no valid application image on a recoverable development board; the target
control pins must remain safe while the bootloader reports the image failure
or resets through its watchdog.

High impedance must be verified with a known weak external pull or equivalent
current measurement, not inferred only from a logic level. Also inspect the
pre-hook ROM window. If any target-facing signal requires a defined level from
the instant reset is released, enforce that level in hardware because project
bootloader code cannot run during the mask-ROM stage.

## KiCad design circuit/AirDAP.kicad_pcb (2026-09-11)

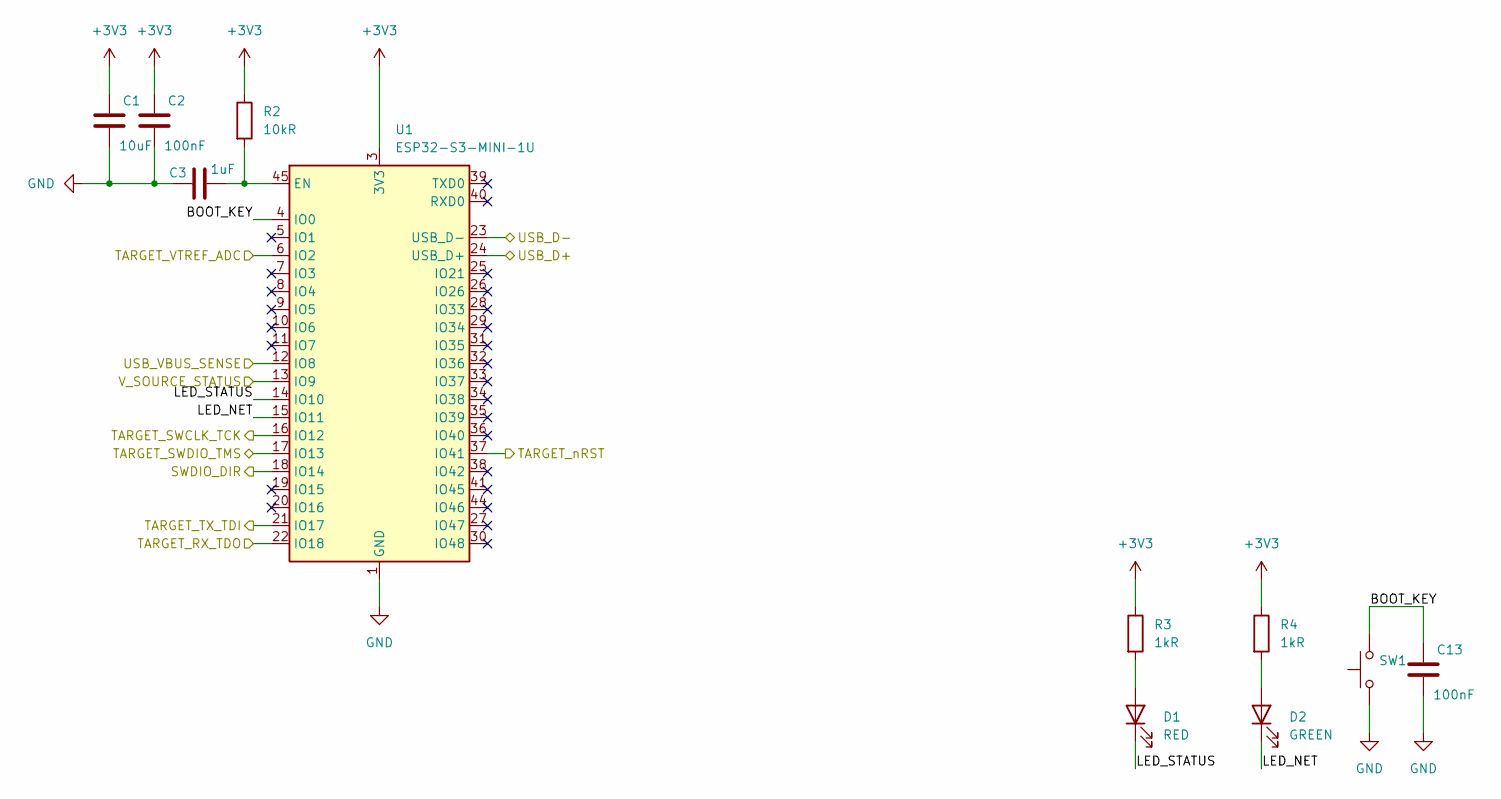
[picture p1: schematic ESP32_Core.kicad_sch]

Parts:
C1: 10uF; C_0402_1005Metric
C2, C13: 100nF; C_0402_1005Metric
C3: 1uF; C_0402_1005Metric
D1: RED; LED_0603_1608Metric
D2: GREEN; LED_0603_1608Metric
R2: 10kR; R_0402_1005Metric
R3, R4: 1kR; R_0402_1005Metric
SW1: SW_Push; SW_Push_SPST_NO_Alps_SKRK
U1: ESP32-S3-MINI-1U; ESP32-S2-MINI-1U

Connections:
+3V3: C1.1, C2.1, R2.1, R3.1, R4.1, U1.3 (3V3); also elsewhere on the board
/ESP32 Core/BOOT_KEY: C13.1, SW1.2, U1.4 (IO0)
/ESP32 Core/LED_NET: D2.1 (K), U1.15 (IO11)
/ESP32 Core/LED_STATUS: D1.1 (K), U1.14 (IO10)
/ESP32 Core/SWDIO_DIR: U1.18 (IO14); also elsewhere on the board
/ESP32 Core/TARGET_RX_TDO: U1.22 (IO18); also elsewhere on the board
/ESP32 Core/TARGET_SWCLK_TCK: U1.16 (IO12); also elsewhere on the board
/ESP32 Core/TARGET_SWDIO_TMS: U1.17 (IO13); also elsewhere on the board
/ESP32 Core/TARGET_TX_TDI: U1.21 (IO17); also elsewhere on the board
/ESP32 Core/TARGET_VTREF_ADC: U1.6 (IO2); also elsewhere on the board
/ESP32 Core/TARGET_nRST: U1.37 (IO41); also elsewhere on the board
/ESP32 Core/USB_D+: U1.24 (USB_D+); also elsewhere on the board
/ESP32 Core/USB_D-: U1.23 (USB_D-); also elsewhere on the board
/ESP32 Core/USB_VBUS_SENSE: U1.12 (IO8); also elsewhere on the board
/ESP32 Core/V_SOURCE_STATUS: U1.13 (IO9); also elsewhere on the board
GND: C1.2, C2.2, C3.1, C13.2, SW1.1, U1.1 (GND), U1.2 (GND), U1.42 (GND), U1.43 (GND), U1.46 (GND), U1.47 (GND), U1.48 (GND), U1.49 (GND), U1.50 (GND), U1.51 (GND), U1.52 (GND), U1.53 (GND), U1.54 (GND), U1.55 (GND), U1.56 (GND), U1.57 (GND), U1.58 (GND), U1.59 (GND), U1.60 (GND), U1.61 (GND), U1.62 (GND), U1.63 (GND), U1.64 (GND), U1.65 (GND); also elsewhere on the board
unnamed: D1.2 (A), R3.2
unnamed: D2.2 (A), R4.2
unnamed: C3.2, R2.2, U1.45 (EN)

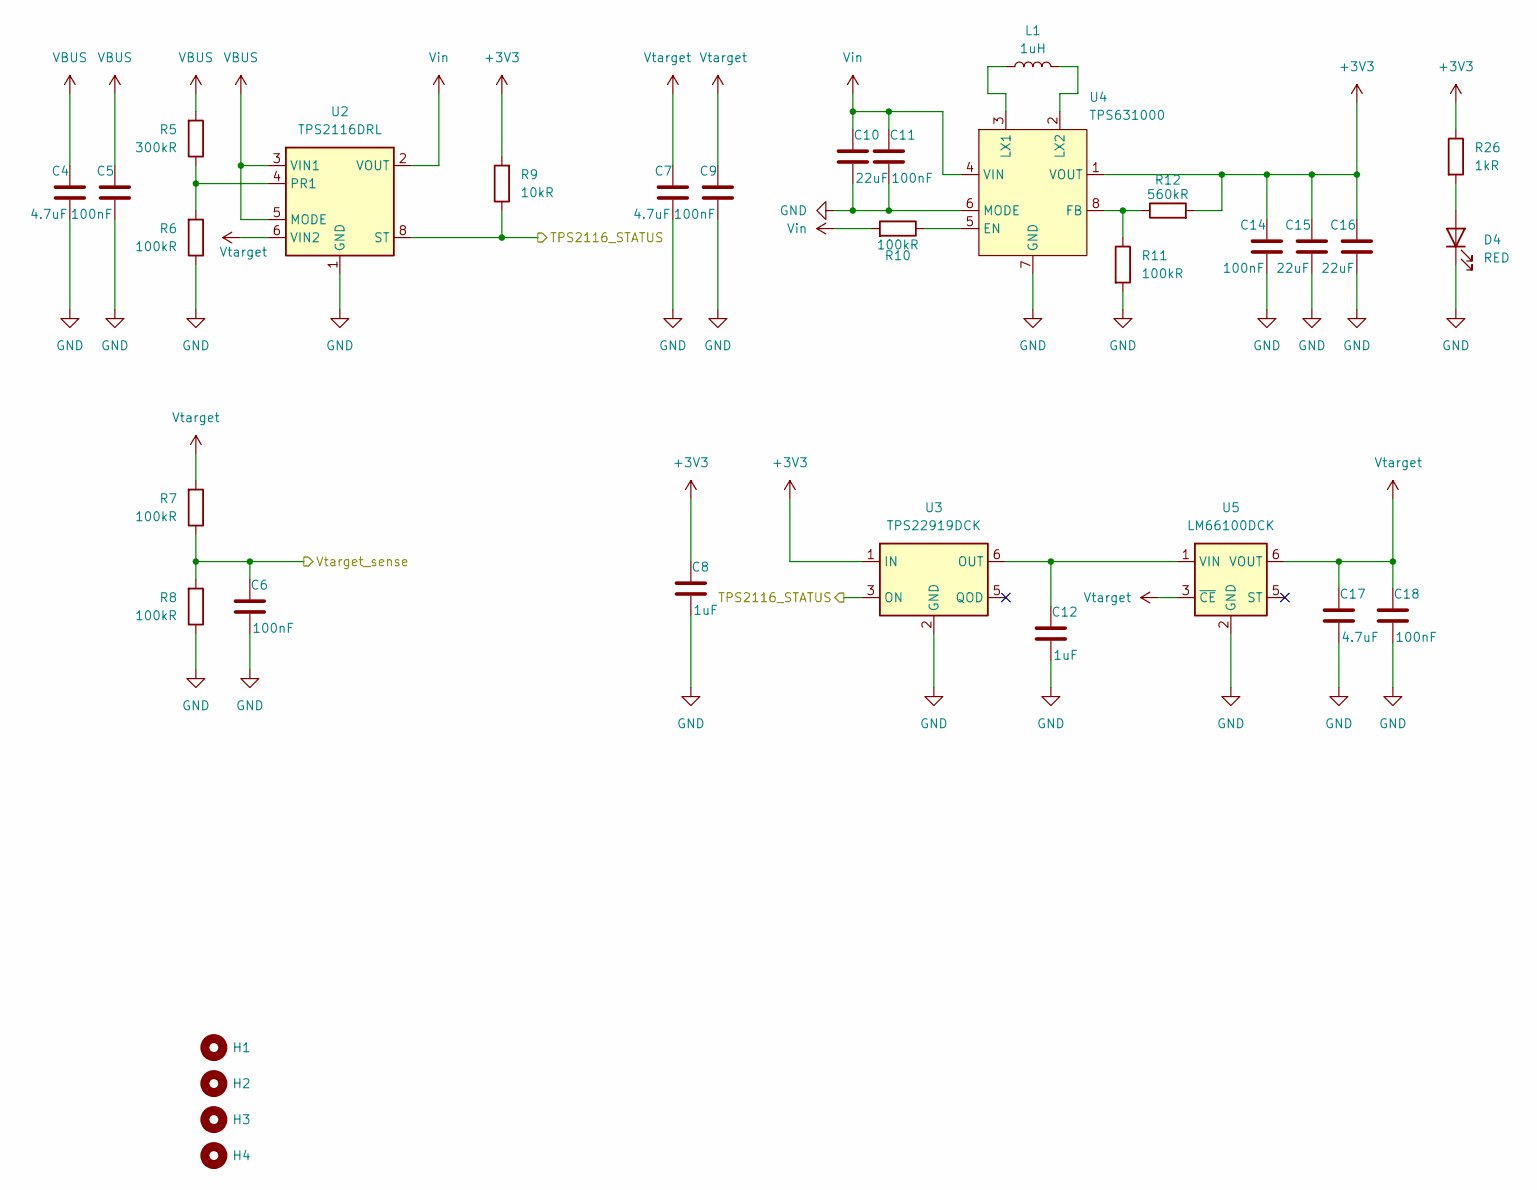
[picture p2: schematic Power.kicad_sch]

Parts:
C4, C7, C17: 4.7uF; C_0402_1005Metric
C5, C6, C9, C11, C14, C18: 100nF; C_0402_1005Metric
C8, C12: 1uF; C_0402_1005Metric
C10, C15, C16: 22uF; C_0603_1608Metric
D4: RED; LED_0603_1608Metric
H1, H2, H3, H4: MountingHole; MountingHole_2.2mm_M2
L1: 1uH; L_1008_2520Metric
R5: 300kR; R_0402_1005Metric
R6, R7, R8, R10, R11: 100kR; R_0402_1005Metric
R9: 10kR; R_0402_1005Metric
R12: 560kR; R_0402_1005Metric
R26: 1kR; R_0402_1005Metric
U2: TPS2116DRL; SOT-583-8
U3: TPS22919DCK; SOT-363_SC-70-6
U4: TPS631000; SOT-583-8
U5: LM66100DCK; SOT-363_SC-70-6

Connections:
+3V3: C8.1, C14.1, C15.1, C16.1, R9.2, R12.2, R26.1, U3.1 (IN), U4.1 (VOUT); also elsewhere on the board
/ESP32 Core/TARGET_VTREF_ADC: C6.1, R7.1, R8.2; also elsewhere on the board
/ESP32 Core/V_SOURCE_STATUS: R9.1, U2.8 (ST), U3.3 (ON); also elsewhere on the board
GND: C4.2, C5.2, C6.2, C7.2, C8.2, C9.2, C10.2, C11.2, C12.2, C14.2, C15.2, C16.2, C17.2, C18.2, D4.1 (K), R6.1, R8.1, R11.2, U2.1 (GND), U3.2 (GND), U4.6 (MODE), U4.7 (GND), U5.2 (GND); also elsewhere on the board
unnamed: D4.2 (A), R26.2
unnamed: R5.1, R6.2, U2.4 (PR1)
unnamed: C12.1, U3.6 (OUT), U5.1 (VIN)
unnamed: R10.1, U4.5 (EN)
unnamed: R11.1, R12.1, U4.8 (FB)
unnamed: L1.1, U4.3 (LX1)
unnamed: L1.2, U4.2 (LX2)
VBUS: C4.1, C5.1, R5.2, U2.3 (VIN1), U2.5 (MODE); also elsewhere on the board
Vin: C10.1, C11.1, R10.2, U2.2 (VOUT), U2.7 (VOUT), U4.4 (VIN)
Vtarget: C7.1, C9.1, C17.1, C18.1, R7.2, U2.6 (VIN2), U5.3 (~CE), U5.6 (VOUT); also elsewhere on the board

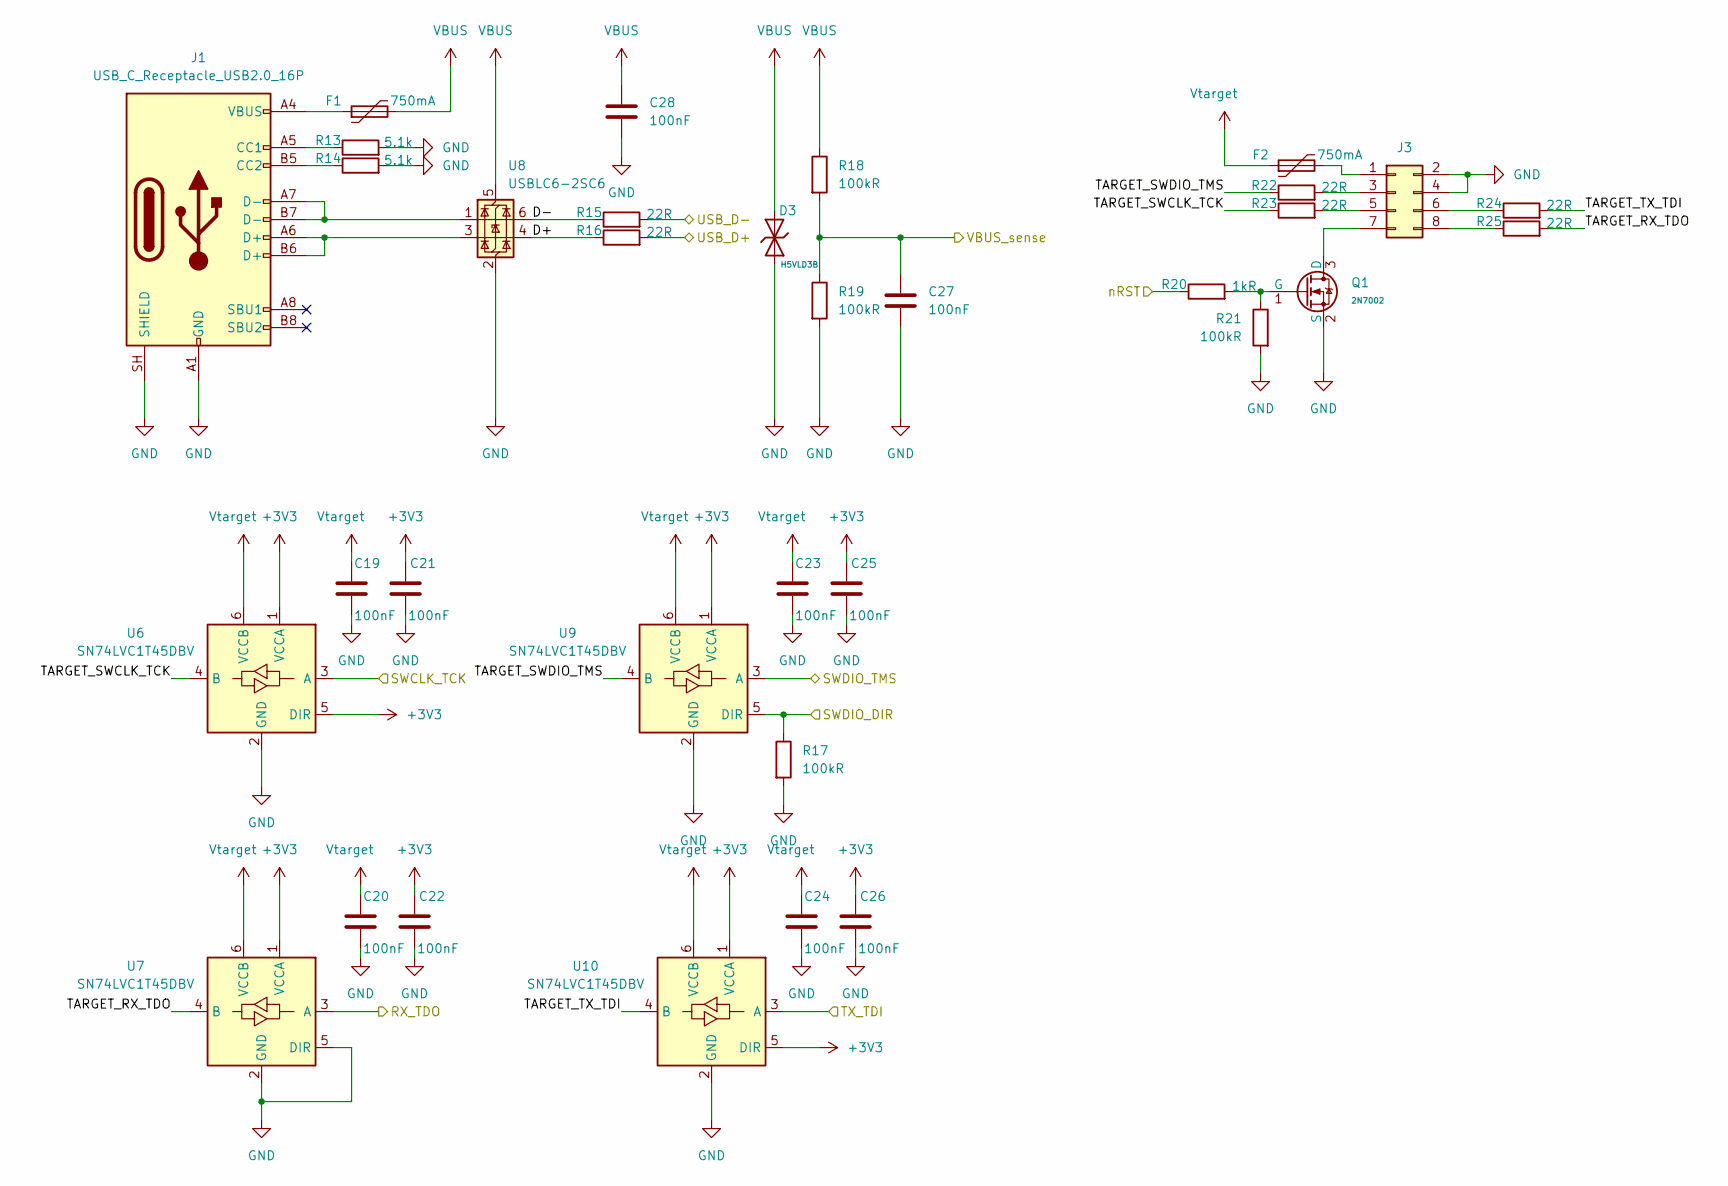
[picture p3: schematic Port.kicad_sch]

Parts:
C19, C20, C21, C22, C23, C24, C25, C26, C27, C28: 100nF; C_0402_1005Metric
D3: H5VLD3B; D_SOD-323; Part H5VLD3B; LCSC C20615805
F1, F2: 750mA; Fuse_0805_2012Metric
J1: USB_C_Receptacle_USB2.0_16P; USB_C_Receptacle_Palconn_UTC16-G
J3: Conn_02x04_Odd_Even; PinHeader_2x04_P2.54mm_Vertical
Q1: 2N7002; SOT-323_SC-70; Part 2N7002; LCSC C8545
R13, R14: 5.1k; R_0402_1005Metric
R15, R16, R22, R23, R24, R25: 22R; R_0402_1005Metric
R17, R18, R19, R21: 100kR; R_0402_1005Metric
R20: 1kR; R_0402_1005Metric
U6, U7, U9, U10: SN74LVC1T45DBV; SOT-23-6
U8: USBLC6-2SC6; SOT-23-6

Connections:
+3V3: C21.1, C22.1, C25.1, C26.1, U6.1 (VCCA), U6.5 (DIR), U7.1 (VCCA), U9.1 (VCCA), U10.1 (VCCA), U10.5 (DIR); also elsewhere on the board
/ESP32 Core/SWDIO_DIR: R17.1, U9.5 (DIR); also elsewhere on the board
/ESP32 Core/TARGET_RX_TDO: U7.3 (A); also elsewhere on the board
/ESP32 Core/TARGET_SWCLK_TCK: U6.3 (A); also elsewhere on the board
/ESP32 Core/TARGET_SWDIO_TMS: U9.3 (A); also elsewhere on the board
/ESP32 Core/TARGET_TX_TDI: U10.3 (A); also elsewhere on the board
/ESP32 Core/TARGET_nRST: R20.1; also elsewhere on the board
/ESP32 Core/USB_D+: R16.2; also elsewhere on the board
/ESP32 Core/USB_D-: R15.2; also elsewhere on the board
/ESP32 Core/USB_VBUS_SENSE: C27.1, R18.2, R19.1; also elsewhere on the board
/Port/D+: R16.1, U8.4 (I/O2)
/Port/D-: R15.1, U8.6 (I/O1)
/Port/TARGET_RX_TDO: R25.2, U7.4 (B)
/Port/TARGET_SWCLK_TCK: R23.1, U6.4 (B)
/Port/TARGET_SWDIO_TMS: R22.1, U9.4 (B)
/Port/TARGET_TX_TDI: R24.2, U10.4 (B)
GND: C19.2, C20.2, C21.2, C22.2, C23.2, C24.2, C25.2, C26.2, C27.2, C28.2, D3.1, J1.A1 (GND), J1.A12 (GND), J1.B1 (GND), J1.B12 (GND), J1.SH (SHIELD), J3.2, J3.4, Q1.2 (S), R13.2, R14.2, R17.2, R19.2, R21.2, U6.2 (GND), U7.2 (GND), U7.5 (DIR), U8.2 (GND), U9.2 (GND), U10.2 (GND); also elsewhere on the board
unnamed: F1.1, J1.A4 (VBUS), J1.A9 (VBUS), J1.B4 (VBUS), J1.B9 (VBUS)
unnamed: J1.A5 (CC1), R13.1
unnamed: J1.B5 (CC2), R14.1
unnamed: J1.A6 (D+), J1.B6 (D+), U8.3 (I/O2)
unnamed: J1.A7 (D-), J1.B7 (D-), U8.1 (I/O1)
unnamed: F2.2, J3.1
unnamed: J3.3, R22.2
unnamed: J3.5, R23.2
unnamed: J3.6, R24.1
unnamed: J3.7, Q1.3 (D)
unnamed: J3.8, R25.1
unnamed: Q1.1 (G), R20.2, R21.1
VBUS: C28.1, D3.2, F1.2, R18.1, U8.5 (VBUS); also elsewhere on the board
Vtarget: C19.1, C20.1, C23.1, C24.1, F2.1, U6.6 (VCCB), U7.6 (VCCB), U9.6 (VCCB), U10.6 (VCCB); also elsewhere on the board

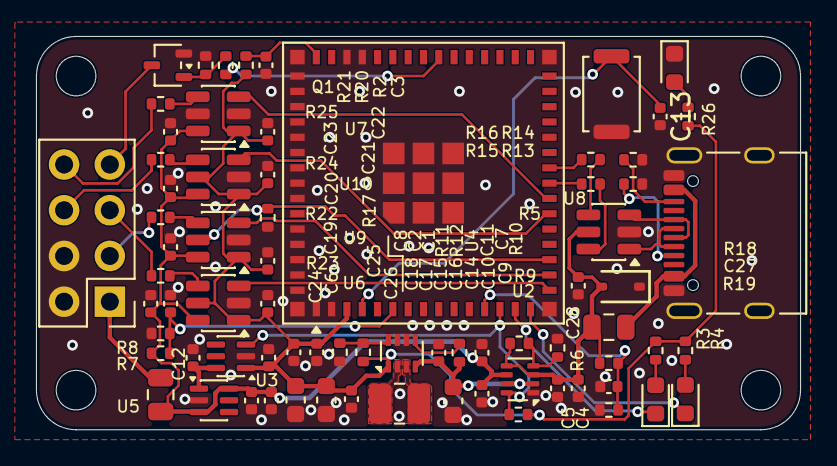
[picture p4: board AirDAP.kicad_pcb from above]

Board: 2 copper layers, 42.5 x 21.8 mm, 78 parts (0 on the bottom side), 47 nets.

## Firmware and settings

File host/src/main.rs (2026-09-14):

use airdap_service::{service::Service, store::Store, web};
use anyhow::{Result, ensure};
use clap::Parser;
use std::{path::PathBuf, time::Duration};
use tokio::sync::watch;

#[derive(Parser, Clone)]
#[command(version, about = "AirDAP 原生 USB/IP 与本机设备管理服务")]
struct Args {
    #[arg(long)]
    data_dir: Option<PathBuf>,
    #[arg(long, default_value_t = 8080)]
    http_port: u16,
    #[arg(long, default_value_t = 3242)]
    usbip_port: u16,
    #[arg(long)]
    no_http: bool,
    #[arg(long)]
    usbip_executable: Option<PathBuf>,
    #[arg(long)]
    windows_service: bool,
    #[arg(long, default_value = "AirDAP")]
    service_name: String,
}
fn main() -> Result<()> {
    let args = Args::parse();
    ensure!(
        args.http_port > 0 && args.usbip_port > 0,
        "端口必须为 1..65535"
    );
    if args.windows_service {
        #[cfg(windows)]
        return scm::dispatch(&args.service_name);
        #[cfg(not(windows))]
        anyhow::bail!("--windows-service 仅适用于 Windows");
    }
    let (stop, rx) = watch::channel(false);
    runtime()?.block_on(async move {
        tokio::spawn(async move {
            #[cfg(unix)]
            {
                let mut term =
                    tokio::signal::unix::signal(tokio::signal::unix::SignalKind::terminate())
                        .expect("SIGTERM handler");
                tokio::select! {_ = tokio::signal::ctrl_c() => {}, _ = term.recv() => {}}
            }
            #[cfg(not(unix))]
            {
                let _ = tokio::signal::ctrl_c().await;
            }
            let _ = stop.send(true);
        });
        run(args, rx, || Ok(())).await
    })
}
fn runtime() -> Result<tokio::runtime::Runtime> {
    Ok(tokio::runtime::Builder::new_multi_thread()
        .worker_threads(2)
        .max_blocking_threads(4)
        .enable_all()
        .build()?)
}
async fn run(
    args: Args,
    mut stop: watch::Receiver<bool>,
    ready: impl FnOnce() -> Result<()>,
) -> Result<()> {
    let path = args.data_dir.unwrap_or_else(|| {
        let root = std::env::var_os(if cfg!(windows) {
            "LOCALAPPDATA"
        } else {
            "XDG_DATA_HOME"
        })
        .map(PathBuf::from)
        .unwrap_or_else(|| {
            PathBuf::from(std::env::var_os("HOME").unwrap_or_else(|| ".".into()))
                .join(".local/share")
        });
        root.join("AirDAP/service")
    });
    let service = Service::new(Store::open(&path)?, args.usbip_port, args.usbip_executable)?;
    let (http_stop, http_rx) = watch::channel(false);
    let web_task = if args.no_http {
        None
    } else {
        let listener = tokio::net::TcpListener::bind(("127.0.0.1", args.http_port)).await?;
        let router = web::router(service.clone(), args.http_port)?;
        eprintln!("AirDAP Web: http://airdap.localhost:{}", args.http_port);
        Some(tokio::spawn(async move {
            let mut rx = http_rx;
            axum::serve(listener, router)
                .with_graceful_shutdown(async move {
                    let _ = rx.wait_for(|v| *v).await;
                })
                .await
        }))
    };
    let maintenance = tokio::spawn(service.clone().maintain());
    service.lifecycle("started");
    let ready_result = ready();
    if ready_result.is_ok() {
        let _ = stop.wait_for(|v| *v).await;
    }
    service.begin_close();
    let _ = http_stop.send(true);
    // Do not abort maintenance or the active job: they may own an in-flight device write.
    let close = service.close().await;
    maintenance.await?;
    if let Some(task) = web_task {
        match tokio::time::timeout(Duration::from_secs(12), task).await {
            Ok(result) => {
                result??;
            }
            Err(_) => eprintln!("HTTP 客户端关闭超时，设备操作已结束"),
        }
    }
    ready_result?;
    service.lifecycle(if close.is_ok() {
        "stopped"
    } else {
        "cleanup-failed"
    });
    close
}

#[cfg(windows)]
mod scm {
    use super::*;
    use std::{
        ffi::OsString,
        sync::{
            Arc,
            atomic::{AtomicBool, Ordering},
        },
    };
    use windows_service::{
        define_windows_service,
        service::{
            ServiceControl, ServiceControlAccept, ServiceExitCode, ServiceState, ServiceStatus,
            ServiceType,
        },
        service_control_handler::{self, ServiceControlHandlerResult},
        service_dispatcher,
    };
    define_windows_service!(entry, service_main);
    pub fn dispatch(name: &str) -> Result<()> {
        service_dispatcher::start(name, entry)?;
        Ok(())
    }
    fn status(state: ServiceState, checkpoint: u32, error: u32) -> ServiceStatus {
        ServiceStatus {
            service_type: ServiceType::OWN_PROCESS,
            current_state: state,
            controls_accepted: if state == ServiceState::Running {
                ServiceControlAccept::STOP | ServiceControlAccept::SHUTDOWN
            } else {
                ServiceControlAccept::empty()
            },
            exit_code: ServiceExitCode::Win32(error),
            checkpoint,
            wait_hint: if matches!(
                state,
                ServiceState::StartPending | ServiceState::StopPending
            ) {
                Duration::from_secs(30)
            } else {
                Duration::ZERO
            },
            process_id: None,
        }
    }
    fn service_main(_: Vec<OsString>) {
        let args = Args::parse();
        let (stop, rx) = watch::channel(false);
        let stopping = Arc::new(AtomicBool::new(false));
        let flag = stopping.clone();
        let handle =
            match service_control_handler::register(
                &args.service_name,
                move |control| match control {
                    ServiceControl::Stop | ServiceControl::Shutdown => {
                        flag.store(true, Ordering::Release);
                        let _ = stop.send(true);
                        ServiceControlHandlerResult::NoError
                    }
                    ServiceControl::Interrogate => ServiceControlHandlerResult::NoError,
                    _ => ServiceControlHandlerResult::NotImplemented,
                },
            ) {
                Ok(h) => h,
                Err(_) => return,
            };
        if handle
            .set_service_status(status(ServiceState::StartPending, 1, 0))
            .is_err()
        {
            return;
        }
        let result = runtime().and_then(|rt| {
            rt.block_on(async {
                let monitor = tokio::spawn(async move {
                    let mut checkpoint = 1;
                    loop {
                        tokio::time::sleep(Duration::from_secs(5)).await;
                        if stopping.load(Ordering::Acquire) {
                            checkpoint += 1;
                            let _ = handle.set_service_status(status(
                                ServiceState::StopPending,
                                checkpoint,
                                0,
                            ));
                        }
                    }
                });
                let result = run(args, rx, || {
                    handle.set_service_status(status(ServiceState::Running, 0, 0))?;
                    Ok(())
                })
                .await;
                monitor.abort();
                result
            })
        });
        let _ =
            handle.set_service_status(status(ServiceState::Stopped, 0, u32::from(result.is_err())));
    }
}

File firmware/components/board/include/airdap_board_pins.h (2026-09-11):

#pragma once

/*
 * AirDAP ESP32-S3 pin assignment.
 *
 * This header intentionally has no ESP-IDF dependencies so the application,
 * bootloader, and host tests all consume the same hardware contract.
 */
enum {
    AIRDAP_PIN_BOOT_KEY = 0,
    AIRDAP_PIN_TARGET_VTREF_ADC = 2,
    AIRDAP_PIN_USB_VBUS_SENSE = 8,
    AIRDAP_PIN_V_SOURCE_STATUS = 9,
    AIRDAP_PIN_LED_STATUS = 10,
    AIRDAP_PIN_LED_NET = 11,
    AIRDAP_PIN_TARGET_SWCLK_TCK = 12,
    AIRDAP_PIN_TARGET_SWDIO_TMS = 13,
    AIRDAP_PIN_SWDIO_DIR = 14,
    AIRDAP_PIN_TARGET_TX_TDI = 17,
    AIRDAP_PIN_TARGET_RX_TDO = 18,
    AIRDAP_PIN_USB_DM = 19,
    AIRDAP_PIN_USB_DP = 20,
    AIRDAP_PIN_TARGET_NRESET = 41,
};

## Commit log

2026-08-28 feat(hardware): complete initial schematic
    Add the ESP32 core, power, and target-port hierarchy and update the project and PCB state from the completed schematic.
    [AirDAP.kicad_pcb, AirDAP.kicad_sch, ESP32_Core.kicad_sch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]
2026-08-29 feat(hardware): update circuit design
    Refine the schematic hierarchy and PCB layout, and ignore generated KiCad manufacturing outputs.
    [AirDAP.kicad_pcb, AirDAP.kicad_sch, ESP32_Core.kicad_sch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]
2026-08-29 fix(hardware): remove stale UART sheet pins
    Align the root-sheet hierarchy with the child schematics and clear the ESP_TX and ESP_RX ERC mismatches.
    [AirDAP.kicad_sch]
2026-08-29 docs(hardware): add GPIO pin mapping
2026-08-29 feat(firmware): add minimal ESP32-S3 project
    [partitions.csv]
2026-08-29 feat(firmware): add target voltage monitoring
2026-08-29 feat(firmware): add target UART bridge
2026-08-29 feat(firmware): expose wired CMSIS-DAP USB device
2026-08-29 test(firmware): add wired HIL verification
2026-08-29 fix(firmware): register WinUSB device interface
2026-08-30 feat(firmware): add USB OTA update flow
    [partitions.csv]
2026-08-30 fix(firmware): align ESP32-S3 SWD transfers
    [swd_engine.c]
2026-08-30 feat(firmware): add shared device identity
2026-08-30 docs(firmware): document shared device identity
2026-08-31 feat(firmware): target 8 MiB flash layout
    [partitions.csv]
2026-08-31 fix(tools): report inaccessible AirDAP devices cleanly
2026-09-01 feat(firmware): add AirDAP v1 frame protocol
2026-09-01 build(firmware): pin network provisioning component
2026-09-01 test(firmware): add Wi-Fi board validation app
2026-09-01 fix(firmware): gate Wi-Fi online state to current DHCP
2026-09-02 fix(firmware): retain mdns alternate interface slot
2026-09-03 feat(firmware): add Security 2 credential injection
    [partitions.csv]
2026-09-03 feat(firmware): publish shared Security 2 credential
    [partitions.csv]
2026-09-03 fix(firmware): erase OTA image incrementally
    [ota_manager.c]
2026-09-06 fix(firmware): defer BOOT_KEY actions until release
    [board.c]
2026-09-06 feat(firmware): add sampled task diagnostics
2026-09-06 feat(firmware): add UART shell status
2026-09-07 feat(tools): add network pairing and TLS probe
2026-09-07 feat(board): add simulated BOOT_KEY input
2026-09-08 feat(tools): add authenticated DAP probe
2026-09-08 fix(firmware): serialize DAP revoke teardown
    [network_dap.c]
2026-09-08 fix(firmware): enforce DAP handshake framing
    [network_dap.c]
2026-09-11 fix(firmware): enable BOOT_KEY internal pull-up
    [board.c]
2026-09-11 fix(provision): avoid Windows BLE pairing delay
    Use an AirDAP BLE transport without OS pairing while retaining Espressif Security 2 provisioning. Reuse discovered BLEDevice objects and clean up failed connections.
    Add regression tests and hardware validation guidance. Ignore local build diagnostics, Python caches, and generated circuit exports.
    Validation: 14 host tests passed; Windows hardware reached Wi-Fi input unpaired with 2.449 s connection/service discovery and 0.557 s Security 2 handshake.
2026-09-11 fix(dap): accept clock configuration before connecting
    [swd_engine.c]
2026-09-11 fix(board): match VBUS conversion to equal resistor divider
    [voltage_monitor.c]
2026-09-11 feat(hardware): update kicad project
    [AirDAP.kicad_pcb, ESP32_Core.kicad_sch, Port.kicad_sch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]
2026-09-11 fix(board): sample VTref on schematic GPIO2
    [airdap_board_pins.h]
2026-09-11 feat(firmware): add shared target UART service
2026-09-11 docs(firmware): describe target UART service
2026-09-11 fix(uart): block idle USB bridge for at least one tick
2026-09-11 fix(board): share successful reset state with DAP
    [board.c]
2026-09-11 feat(protocol): unify UART and board control opcodes and errors
2026-09-12 feat(uart): define authenticated control payloads and bounded dispatch
2026-09-12 feat(network): serve UART TCP 3261 through shared authenticated lifecycle
2026-09-12 test(uart): add authenticated loopback and USB coexistence probes
2026-09-12 feat(control): authorize reset and power commands on TCP 3260
    [network_dap.c]
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2026-09-12 fix(usb_device): 延后 CDC 配置对 UART TX 的占用至 DTR 打开
    DTR 未激活时仅缓存 line coding，避免枚举请求创建无法正常释放的 USB TX owner；DTR 打开后再申请所有权并应用配置，保留 NETWORK owner 的非抢占行为。
    验证：新增枚举与关闭后配置回归在旧实现下失败；修复后 ctest --test-dir /tmp/airdap-uart-cdc-owner-red --output-on-failure 通过。
2026-09-12 feat(ota_manager): 接入认证网络 OTA 与连接级清理
    复用共享 OTA 状态机串行化 USB 和网络更新，绑定发起连接并在 Flash 入口及镜像验证后重新检查认证。写入前释放 DAP/UART，提交后保持挂起，断线只清理对应上传。新增 CONTROL 协议、生命周期测试和运行分区校验。
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2026-09-12 fix(wifi_manager): 将认证超时归入认证失败诊断
    实板错误密码测试收到 WIFI_REASON_AUTH_EXPIRE（2），原实现将其归为 transient。按 ESP-IDF 的认证超时/失效定义补齐分类，保持重连退避和状态迁移不变。该原因码不等同于密码错误。新增分类回归旧实现失败，修复后 wifi_manager 的两个 CTest 均通过。
2026-09-12 test(hil): 增加 pyOCD 无线烧录与重连回读验收
    复用认证 TCP 3260 和 pyOCD CMSIS-DAP 引擎，提供扇区烧录、备份及两次逐字节回读工具，不枚举 USB 探针。
    验证：Windows 7 项单元测试、WSL 5 套 CTest 通过；STM32F103C8 在 500 kHz、1 MHz、5 MHz 实际无线擦写及复位重连回读通过，测试范围已恢复。
2026-09-12 feat(ble_provisioning): 增加单击双击与长按识别状态机
    增加按下和释放消抖、单击等待及双击识别，保留原有长按释放确认行为。单击和双击只记录日志，暂不绑定设备操作。
    验证：7 套相关主机测试共 15 项 CTest 通过；ESP-IDF 标准构建及 bootloader、OTA 布局产物门禁通过。未执行实板按键验收。
2026-09-12 feat(ble_provisioning): 使用 STATUS 闪烁反馈按键操作
    替换原有绿灯和红灯长按提示。普通按住不亮；单击闪一次、双击闪两次，3 秒慢闪、10 秒快闪。由按键任务统一写入 LED，消抖保留闪烁相位，写入失败重试且不阻断按键事件。
    验证：7 套相关主机测试共 16 项 CTest 通过；ESP-IDF 标准构建及 bootloader、OTA 布局门禁通过。未烧录或进行实板灯效验收。
2026-09-12 feat(mode_state): 支持空闲时切换 USB 与无线 DAP
    增加 AUTO、USB、NETWORK 运行期选择并保留物理 USB 状态及认证检查。选择需要无 DAP owner 且无 OTA，通过 ownership reservation 和策略版本校验协调并发；USB 接入及抢占期间拒绝跨越的手动选择。
    验证：mode_state、dap_backend、debug_shell_swd_probe、network_control、ota_manager 主机测试通过。
2026-09-12 feat(ble_provisioning): 增加 2、6、10 秒长按与三级灯效
    将原 3 秒门槛改为 2 秒，新增 6 秒门槛，松开时仅返回最高档动作。STATUS 分别按 500、200、60 ms 半周期闪烁，普通按住保持熄灭，6 秒动作默认留空。
    验证：ble_provisioning、debug_shell_button 与 mode_state 主机测试通过，覆盖阈值边界、释放保护和三级 LED 输出。
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2026-09-12 feat(usb_device)!: 用完整手势模拟替换按键按下松开命令
    BREAKING CHANGE: button press/release 改为 button simulate single|double|hold2|hold6|hold10，自动完成松开；button status 改为报告模拟手势或 idle。
2026-09-12 fix(usb_device): 固定声明按键模拟组件依赖
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2026-09-13 feat(mode_state): 按通道选择禁用网络 DAP 和 UART
    USB 生效时拒绝网络 DAP 请求并关闭 UART 监听及已有连接。共享 TCP 3260 保留管理和 OTA，AUTO 随 USB 枚举状态切换。
2026-09-13 feat(usb_device): 网络模式下撤下有线 DAP 和 UART 接口
    切换时释放 USB 会话并重新枚举，网络模式仅保留独立 debug shell；切回 USB 或 AUTO 恢复原布局。同步适配 shell 客户端的两种 PID 和接口编号，并补充描述符、生命周期测试与实机验证步骤。
2026-09-13 fix(usb_device): 修复网络模式 shell 的 Windows 驱动绑定
2026-09-13 fix(usb_device): 启用 VBUS 检测以识别独立供电时拔线
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2026-09-13 feat(mode_state): 保存通道模式并支持 NETWORK/AUTO 切换
    在 NVS 提交成功后发布模式，启动时在 USB 初始化前恢复所选通道。AUTO 拔插仅改变活动通道，不重复写入 Flash。保存失败保留当前选择。
    验证：mode_state、app_main、DAP/OTA 与 USB 相关 CMake/CTest 检查通过；idf.py build 通过 bootloader 和 OTA 布局门禁。断电恢复及启动枚举尚未实机验证。
2026-09-13 feat(button_config): 默认双击切换 NETWORK/AUTO 并迁移旧绑定
    追加 dap-network-auto-toggle 命令，保留旧 dap-toggle。将版本 1 的双击默认绑定一次性迁移到新命令，保留其他自定义绑定；版本 2 允许主动绑回旧命令。
    验证：button_config、ble_provisioning、debug_shell_button 的 CMake/CTest 检查通过；完整主机回归 50 个套件、66 项 CTest 检查通过。尚未烧录或执行实机按键与断电验证。
2026-09-13 fix(mode_state): 修复 OTA 初始化后恢复模式导致启动回滚
    恢复启动模式时保留 OTA_RESET 产生的策略计数，仅校验实际运行状态，避免正常初始化被判为非法状态。启动测试接入真实模式模块并覆盖三种持久化路由，补充 OTA_RESET 顺序回归。
    验证：mode_state、app_main 先复现断言失败，修复后与 ota_manager 的 CMake/CTest 检查通过。
2026-09-13 feat(tools): 将网络 DAP 和 UART 映射为本机 USB/IP 设备
    复用 TLS-PSK 客户端并绑定共享认证会话，提供 CMSIS-DAP v2、CDC 和 WinUSB 描述符。对取消、断线和有界队列进行处理，避免重放不确定的写入。
    验证：airdap_usbip 主机测试在 Windows/Linux 通过；usbip_windows.py 和 usbip_linux.py 使用模拟网络后端，通过真实 VHCI 驱动完成枚举、DAP_Info 和串口回环。实物无线烧录尚未验证。
2026-09-13 feat(tools): 添加 Windows 和 Linux USB/IP 后台启动配置
    Windows 使用当前用户计划任务和 pythonw，提供安装、启停、状态和移除操作；Linux 提供 systemd 用户服务。后台进程只启动本机桥接，虚拟设备仍由 USB/IP 客户端显式挂载。
    验证：ctest 后台脚本测试通过（模拟计划任务 API）；PowerShell 语法检查和 systemd-analyze --user verify 通过。未安装持久后台任务或执行登录自启验收。
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2026-09-13 fix(tools): 修复 USB/IP 存在活动连接时停止阻塞
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2026-09-13 fix(host): 补齐系统服务中的蓝牙配网加载环境
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2026-09-13 fix(host): 允许桥接运行时上传并检查 OTA 镜像
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2026-09-13 fix(host-native): 核对驱动自动移除后的 USB 挂载状态
2026-09-13 fix(host-native): 等待 USB OTA 重启后的完整枚举确认
2026-09-13 fix(host-native): 在 Windows 上显式建立并保持蓝牙 GATT 会话
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2026-09-15 docs: 清理 docs 目录并修正文档入口
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
